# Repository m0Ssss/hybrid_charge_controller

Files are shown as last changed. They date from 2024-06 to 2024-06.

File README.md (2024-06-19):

# hybrid_charge_controller development board version 1 and (energy meadow) version 2 *Work In Progress* 
Low voltage solar/wind/ other generator hybrid charge controller -  power conditioning circuit development board *version 1), and version 2 with built in charger. 
<br>MPPT (Maximum Power point tracking) using ST's SPV1040 IC
<br> 0v charging function to regenerate over-discharged batteries that can no longer be charged with conventional chargers. 
<br>0.3v - 30 volt in AC or DC 
<br>5v Out
<br>Temperature sensor for over and under temperature protection
<br> over voltage, over current, over discharge protection
<br> Constant Current and Constant voltage charging
<br>still a lot of issues need to e resolved. e.g. wrong placement of load in relation to charge protection IC (BQ2980), footprint wrong for SPV1040... etc. Issues in Bill of Materials. 
<br>Designed as part of the Windternet Project with Regenerative Energy Communities + Solar Internet, where we are wanting to run a raspberry pi 0 server on the experimental farm "VXO Farmlab" in Sweden. 

https://regenerative-energy-communities.org/

https://solarinternet.org/

Check out the latter for documentation on the low energy server side of things. 
<br> <br> space for both 18650 batteries or LIPO with JST connector;
<br> The plan is to regenerate over-discharged batteries with renewable energy. We find a lot of 18650s in the e-waste bins.
<br> We made a large input voltage range to allow for many different types of generators; specifically we wanted to design for e-waste motors and other discarded materials (e.g. magnets from harddrives and copper wire from old relays) to be reconditioned into wind generators. 

PCB manufactured by PCBway. SMD components reflow soldered on standard kitchen hotplate with low temperature solder paste. 
We have been trying out using mycelium as a material for turbine blades- documentation can be found here: https://titipi.org/wiki/index.php/Unfolding:SporesandMore

<br> A massive thanks to Urs Gaudenz GaudiLabs for the support, assistance and motivation in designing these 2 (my first 2) PCBs.

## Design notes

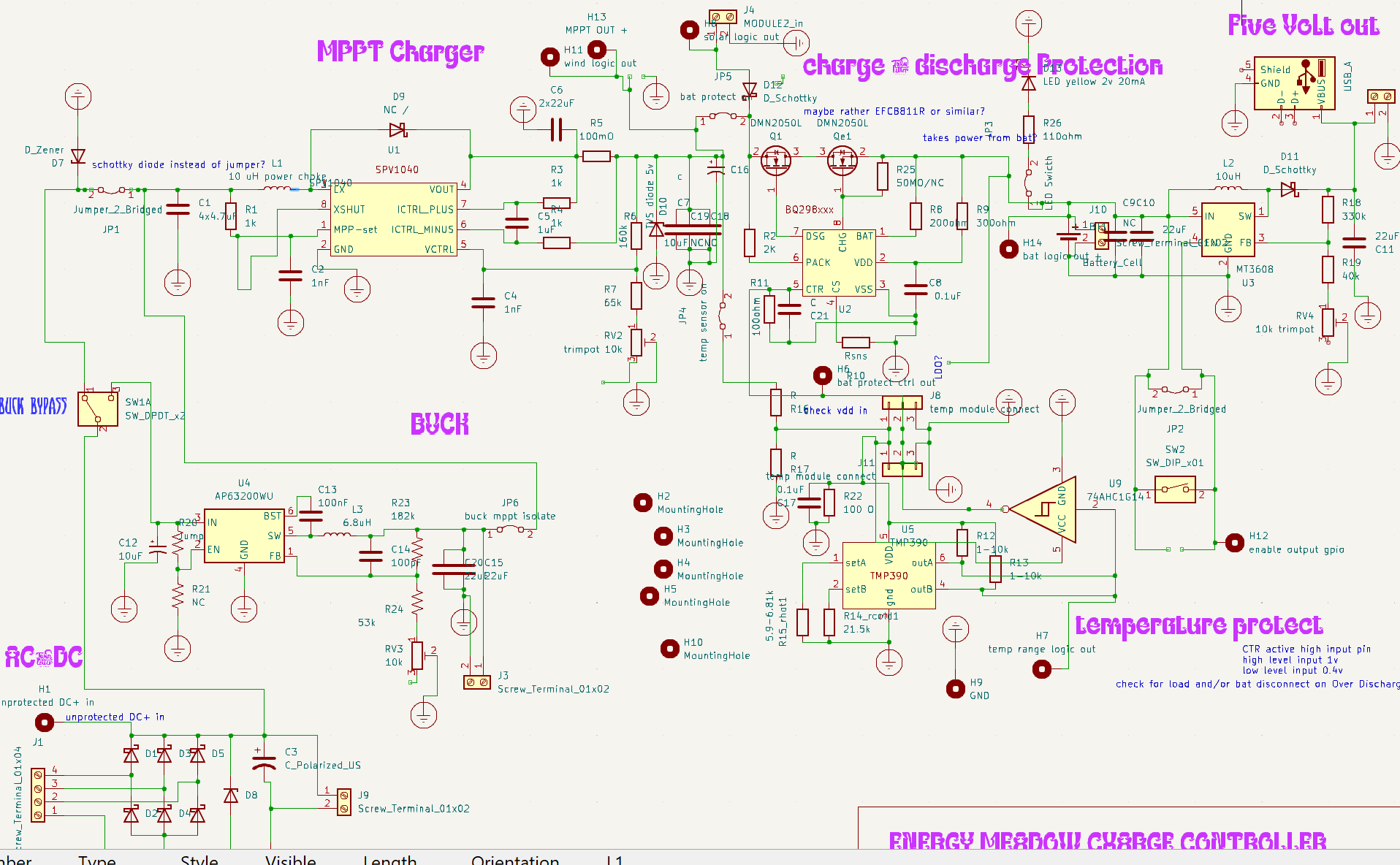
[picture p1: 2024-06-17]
energy meadow schematic.png

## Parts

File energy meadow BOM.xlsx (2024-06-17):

# | Reference | Qty | Value | Footprint | order | own stock | mouser link
1 | 5VOUT1 | 1 | USB_A | Connector_USB:USB_A_TE_292303-7_Horizontal | x |  | https://www.mouser.se/ProductDetail/649-87583-0010BHLF
2 | BT1 | 1 | Battery_Cell | Battery:BatteryHolder_Keystone_1042_1x18650 |  | x
3 | C1 | 1 | 4x4.7uF | Capacitor_SMD:C_0805_2012Metric_Pad1.18x1.45mm_HandSolder | x
4 | C2, C4 | 2 | 1nF | Capacitor_SMD:C_0805_2012Metric_Pad1.18x1.45mm_HandSolder | x
5 | C3 | 1 | C_Polarized_US | Capacitor_THT:CP_Radial_D5.0mm_P2.50mm |  | x
6 | C5 | 1 | 1uF | Capacitor_SMD:C_0805_2012Metric_Pad1.18x1.45mm_HandSolder | x
7 | C6 | 1 | 2x22uF | Capacitor_SMD:C_0805_2012Metric_Pad1.18x1.45mm_HandSolder | x |  | https://www.mouser.se/ProductDetail/187-CL21A226MQQNNNE
 | C7 |  | 10uF | _0805 | x
8 | C9, C18, C19 | 3 | NC | Capacitor_SMD:C_0805_2012Metric_Pad1.18x1.45mm_HandSolder |  |  | https://www.mouser.se/ProductDetail/Samsung-Electro-Mechanics/CL21A106KOQNNNE?qs=349EhDEZ59qKIX0T0PKtPw%3D%3D
9 | C8, C17, C13 | 3 | 0.1uF | Capacitor_SMD:C_0805_2012Metric_Pad1.18x1.45mm_HandSolder | x |  | https://www.mouser.se/ProductDetail/KYOCERA-AVX/KGM21NR71H104KT?qs=Jm2GQyTW%2Fbj%252BykwLLGtT1A%3D%3D
10 | C10, C11 | 2 | 22uF | Capacitor_SMD:C_0805_2012Metric_Pad1.18x1.45mm_HandSolder | x |  | https://www.mouser.se/ProductDetail/187-CL21A226MQQNNNE
11 | C12 | 1 | 10uF | Capacitor_THT:CP_Radial_D4.0mm_P1.50mm |  | x
12 | C13 | 1 | 100nF (0.1uF) | Capacitor_SMD:C_0805_2012Metric_Pad1.18x1.45mm_HandSolder | x
13 | C14 | 1 | 100pF | Capacitor_SMD:C_0805_2012Metric_Pad1.18x1.45mm_HandSolder | x |  | https://www.mouser.se/ProductDetail/Samsung-Electro-Mechanics/CL21C101JBANNNC?qs=349EhDEZ59qraa25nnlm1Q%3D%3D
14 | C15, C20 | 2 | 22uF | Capacitor_THT:CP_Radial_D4.0mm_P1.50mm
15 | C16 | 1 | c | Capacitor_THT:CP_Radial_D4.0mm_P1.50mm
16 | C21 | 2 | C | Capacitor_SMD:C_0805_2012Metric_Pad1.18x1.45mm_HandSolder
17 | D1, D2, D3, D4, D5, D6 | 6 | Schottky 40V 3A SB340-E3/73 | Diode_THT:D_5W_P12.70mm_Horizontal | x |  | https://www.mouser.se/ProductDetail/625-SB340-E3-73
18 | D7 | 1 | D_Zener 4.3V 3W | Diode_SMD:D_Powermite2_AK | x |  | https://www.mouser.se/ProductDetail/onsemi/1SMB5916BT3G?qs=y2kkmE52mdPX9LGvTFZgqQ%3D%3D
19 | D8 | 1 | Zener 30V 5W | Diode_SMD:D_Powermite2_AK | x |  | https://www.mouser.se/ProductDetail/Micro-Commercial-Components-MCC/SMBJ5363B-TP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
20 | D9 | 1 | NC / | Diode_SMD:D_0805_2012Metric_Pad1.15x1.40mm_HandSolder
21 | D10 | 1 | TVS diode 5v | Diode_SMD:D_Powermite_AK | x |  | https://www.mouser.se/ProductDetail/637-SMF5.0A
22 | D11, D12 | 2 | D_Schottky 320mV 2A | Diode_SMD:D_0805_2012Metric_Pad1.15x1.40mm_HandSolder | x |  | https://www.mouser.se/ProductDetail/Toshiba/CUHS20S40H3F?qs=PqoDHHvF6497gY1sWcBa1Q%3D%3D
23 | D13 | 1 | LED yellow 2v 20mA | LED_SMD:LED_0805_2012Metric_Pad1.15x1.40mm_HandSolder | x |  | https://www.mouser.se/ProductDetail/604-APT2012SYCK
35 | J1 | 1 | Screw_Terminal_01x04 | TerminalBlock_MetzConnect:TerminalBlock_MetzConnect_Type055_RT01504HDWU_1x04_P5.00mm_Horizontal | x |  | https://www.mouser.se/ProductDetail/490-TB001-500-04BE
36 | J2, J3, J9 | 3 | Screw_Terminal_01x02 | TerminalBlock_MetzConnect:TerminalBlock_MetzConnect_Type059_RT06302HBWC_1x02_P3.50mm_Horizontal | x |  | https://www.mouser.se/ProductDetail/490-TB001-500-02BE
37 | J4 | 1 | MODULE2_in | TerminalBlock_MetzConnect:TerminalBlock_MetzConnect_Type059_RT06302HBWC_1x02_P3.50mm_Horizontal | x |  | same as above
38 | J8, J11 | 2 | temp module connect | Connector_PinHeader_2.00mm:PinHeader_1x03_P2.00mm_Vertical | x |  | https://www.mouser.se/ProductDetail/649-1012937890202BLF
39 | J10 | 1 | Screw_Terminal_01x02 | Connector_JST:JST_PH_S2B-PH-K_1x02_P2.00mm_Horizontal | x |  | https://www.mouser.se/ProductDetail/485-1769
40 | JP1, JP2 | 2 | Jumper_2_Bridged | TestPoint:TestPoint_2Pads_Pitch2.54mm_Drill0.8mm | x |  | https://www.mouser.se/ProductDetail/806-SX1100-B
41 | JP3 | 1 | LED Swicth | TestPoint:TestPoint_2Pads_Pitch2.54mm_Drill0.8mm | x
42 | JP4 | 1 | temp sensor on | TestPoint:TestPoint_2Pads_Pitch2.54mm_Drill0.8mm | x
43 | JP5 | 1 | bat protect on | TestPoint:TestPoint_2Pads_Pitch2.54mm_Drill0.8mm | x
44 | JP6 | 1 | buck mppt isolate | TestPoint:TestPoint_2Pads_Pitch2.54mm_Drill0.8mm | x |  | as above
45 | L1 | 1 | 10 uH power choke | Inductor_SMD:L_6.3x6.3_H3 | x |  | https://www.mouser.se/ProductDetail/791-WLPM545230M100LC
46 | L2 | 1 | 10uH | Inductor_SMD:L_6.3x6.3_H3 | x |  | as above
47 | L3 | 1 | 6.8uH | Inductor_SMD:L_6.3x6.3_H3 | x |  | https://www.mouser.se/ProductDetail/Bourns/SRN6045-6R8Y?qs=opBjA1TV901hgVnK%252Bmh76Q%3D%3D
48 | Q1, Qe1 | 2 | DMN2050L | Package_TO_SOT_SMD:SOT-23 | x |  | https://www.mouser.se/ProductDetail/621-DMN2050L-7
49 | R1, R3, R4 | 3 | 1k | Resistor_SMD:R_0805_2012Metric_Pad1.20x1.40mm_HandSolder | x |  | https://www.mouser.se/ProductDetail/Walsin/WR08X102-JTL?qs=sGAEpiMZZMtlubZbdhIBIO6gLQ25xNI8eLjbeM8ucQM%3D
50 | R2 | 1 | 2K | Resistor_SMD:R_0805_2012Metric_Pad1.20x1.40mm_HandSolder | x |  | https://www.mouser.se/ProductDetail/SEI-Stackpole/RNCP0805FTD2K00
51 | R5 | 1 | 100mO | Resistor_SMD:R_0805_2012Metric_Pad1.20x1.40mm_HandSolder | x |  | https://www.mouser.se/ProductDetail/667-ERJ-6DSJR10V
52 | R6 | 1 | 160k | Resistor_SMD:R_0805_2012Metric_Pad1.20x1.40mm_HandSolder | x |  | https://www.mouser.se/ProductDetail/603-RT0805FRE07160KL
53 | R7 | 1 | 65k | Resistor_SMD:R_0805_2012Metric_Pad1.20x1.40mm_HandSolder | X 64.9k |  | https://www.mouser.se/ProductDetail/603-RT0805FRE0764R9L
54 | R8 | 1 | 200ohm | Resistor_SMD:R_0805_2012Metric_Pad1.20x1.40mm_HandSolder | x |  | https://www.mouser.se/ProductDetail/667-ERJ-P06J201V
55 | R9 | 1 | 300ohm | Resistor_SMD:R_0805_2012Metric_Pad1.20x1.40mm_HandSolder | x |  | https://www.mouser.se/ProductDetail/667-ERJ-P06J301V
56 | R10 | 1 | Rsns | Resistor_SMD:R_0805_2012Metric_Pad1.20x1.40mm_HandSolder
57 | R11 | 1 | 100ohm | Resistor_SMD:R_0805_2012Metric_Pad1.20x1.40mm_HandSolder
58 | R12, R13 | 2 | 1-10k | Resistor_SMD:R_0805_2012Metric_Pad1.20x1.40mm_HandSolder | x 1k
59 | R14_rcold1 | 1 | 21.5k | Resistor_SMD:R_0805_2012Metric_Pad1.20x1.40mm_HandSolder | x |  | https://www.mouser.se/ProductDetail/Panasonic/ERJ-P06F2152V?qs=sWbhZyXmMVdrML%2F4AwC6Xw%3D%3D
60 | R15_rhot1 | 1 | 5.9-6.81k | Resistor_SMD:R_0805_2012Metric_Pad1.20x1.40mm_HandSolder | X 6.19k |  | https://www.mouser.se/ProductDetail/667-ERJ-6ENF6191V
61 | R16, R17 | 2 | R | Resistor_SMD:R_0805_2012Metric_Pad1.20x1.40mm_HandSolder
62 | R18 | 1 | 330k | Resistor_SMD:R_0805_2012Metric_Pad1.20x1.40mm_HandSolder | x |  | https://www.mouser.se/ProductDetail/603-RT0805FRE07330KL
63 | R19 | 1 | 40k | Resistor_SMD:R_0805_2012Metric_Pad1.20x1.40mm_HandSolder | X 40.2k |  | https://www.mouser.se/ProductDetail/603-RT0805FRE0740K2L
64 | R20 | 1 | Jump | Resistor_SMD:R_0805_2012Metric_Pad1.20x1.40mm_HandSolder
65 | R21 | 1 | NC | Resistor_SMD:R_0805_2012Metric_Pad1.20x1.40mm_HandSolder
66 | R22 | 1 | 100 O | Resistor_SMD:R_0805_2012Metric_Pad1.20x1.40mm_HandSolder | x |  | https://www.mouser.se/ProductDetail/667-ERJ-P06J101V
67 | R23 | 1 | 182k | Resistor_SMD:R_0805_2012Metric_Pad1.20x1.40mm_HandSolder | x |  | https://www.mouser.se/ProductDetail/603-RT0805FRE07182KL
68 | R24 | 1 | 53k | Resistor_SMD:R_0805_2012Metric_Pad1.20x1.40mm_HandSolder | X 53.6 |  | https://www.mouser.se/ProductDetail/603-RT0805FRE0753K6L
69 | R25 | 1 | 50MO/NC | Resistor_SMD:R_0805_2012Metric_Pad1.20x1.40mm_HandSolder
70 | R26 | 1 | 110ohm | Resistor_SMD:R_0805_2012Metric_Pad1.20x1.40mm_HandSolder | x |  | https://www.mouser.se/ProductDetail/71-CRCW0805110RFKEAC
71 | RV2 | 1 | trimpot 10k | Potentiometer_SMD:Potentiometer_ACP_CA6-VSMD_Vertical | x |  | https://www.mouser.se/ProductDetail/774-06TR4FA103DPR
72 | RV3 | 1 | 10k | Potentiometer_SMD:Potentiometer_ACP_CA6-VSMD_Vertical | x
73 | RV4 | 1 | 10k trimpot | Potentiometer_SMD:Potentiometer_ACP_CA6-VSMD_Vertical | x |  | as above
74 | SW1 | 1 | SW_DPDT_x2 | GaudiLabsFootPrints:SWITCH_SLIDE | x | GaudiStock | https://www.mouser.se/ProductDetail/612-EG1218A
75 | SW2 | 1 | SW_DIP_x01 | GaudiLabsFootPrints:SWITCH_SLIDE | x | x | as above
76 | U1 | 1 | SPV1040 | Package_SO:TSSOP-8_3x3mm_P0.65mm
77 | U2 | 1 | BQ2980 | Package_DFN_QFN_AKL:Texas_X2QFN-8_1.5x1.5mm
78 | U3 | 1 | MT3608 | Package_TO_SOT_SMD:SOT-23-6
79 | U4 | 1 | AP63200WU | Package_TO_SOT_SMD:TSOT-23-6
80 | U5 | 1 | TMP390 | Package_TO_SOT_SMD:SOT-563
81 | U9 | 1 | 74AHC1G14 | Package_TO_SOT_SMD:SOT-353_SC-70-5_Handsoldering

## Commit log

2024-06-17 Add files via upload
    version 2 : Energy Meadow
    [SPV simple and cheap.kicad_sch]
2024-06-17 Rename SPV simple and cheap.kicad_pcb to energymeadow.kicad
2024-06-17 Update and rename SPV simple and cheap.kicad_sch to energymeadow.kicad_sch
    [energymeadow.kicad_sch]
2024-06-17 Rename SPV simple and cheap.kicad_pro to energymeadow.kicad_pro
2024-06-17 Add files via upload
    Bill of Materials
    [energy meadow BOM.xlsx]
2024-06-17 Add files via upload
    fabrication by PCBWay
2024-06-17 Add files via upload
    schematic
